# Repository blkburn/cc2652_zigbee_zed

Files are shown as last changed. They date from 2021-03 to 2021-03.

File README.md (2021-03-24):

# Zigbee End Device based on the CC2652R1

This is the complete hardware and software design of a zigbee end device (ZED) designed to be run from a same CR2032 button cell battery.

Texas Instruments Code Composer and the Simplelink SDK is used for development; based on the zed_temperaturesensor_CC26X2R1_LAUNCHXL_tirtos_ccs project.

The hardware design replicates the Launchpad-CC26x2R1 development board as much as possible.

The CC2652R1 is an ultra-low power ARM Cortex process with support for a number of wireless protocols, such as; Thread, Zigbee®, Bluetooth® 5.1 Low Energy, IEEE 802.15.4, IPv6-enabled (6LoWPAN), as well as proprietary protocols including TI 15.4-Stack (2.4 GHz), and simultaneous multi-protocol operation via Dynamic Multiprotocol Manager (DMM).

Development baord power consuption is in line with published datasheet power comsumption figures, allowing the zigbee end device to last many months or years on a single CR2032 battery.

The development board can interface various I2C sensors; a pin breakout is provided to interface the many cheap sensors available on-line. An Adafruit 4-pin STEMMA connector is also provide to connect to an I2C device in their range.

A JTAG header is provided to interface XDS110 (or better) debuggers. A CC1352 Launchpad with built-in XDS110 has been used to debug the development boards.

4-pin bootloader

## Master branch is currently built with:
* CCStudio version: 10.1.1.00004 
* Simplelink_cc13x2_26x2_sdk_4_30_00_54

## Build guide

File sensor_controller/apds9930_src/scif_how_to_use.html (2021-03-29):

# Sensor Controller Studio

## SCIF Driver - How to Use

Introduction

This guide describes how to use the Sensor Controller Interface driver (SCIF) generated from the following Sensor Controller project:

- Project name: APDS9930 I2C Digital Proximity and Ambient Light Sensor
- Project file: C:/Users/BigBob/github/sensor_controller/adps9930.scp
- Operating system: TI-RTOS
- Target chip: CC2652R1F, package QFN48 7x7 RGZ, revision E (2.1)

The guide is tailored for this project, and contains code snippets that you can copy and paste directly into your application.

Preparation

Sensor Controller task code cannot be debugged from the application IDE (IAR EWARM or CCS).

Use Task Testing, Task Debugging and/or Run-Time Logging in Sensor Controller Studio to make sure that your Sensor Controller task(s) work as expected, before you start integrating the SCIF driver into the application.

Getting Started

Follow these steps to start integrating the SCIF driver into your application:

- Add the generated SCIF driver to the application project
- Include the SCIF driver header file
- Add callback functions
- Initialize the SCIF driver
- Start Sensor Controller tasks (simplified)
- Access Sensor Controller data structures from the application
- Handle Sensor Controller ALERT interrupts

Further Integration

These sections cover additional SCIF driver features and other information that can be helpful when integrating the SCIF driver:

- Task control
  - Wait for the previous task control operation to finish
  - Start or restart Sensor Controller tasks
  - Stop Sensor Controller tasks
  - Run Sensor Controller tasks once
  - Trigger the execution code block manually
- Share I/O pins between the Sensor Controller and the application
- Use project specific definitions in the application
- Uninitialize the SCIF driver
- Run the Sensor Controller Studio code generator in the application pre-build step
- Generate Doxygen documentation for the SCIF driver

Getting Started

This section describes how to add and start integrating the SCIF driver into an existing System CPU application.

It is assumed that all the code snippets below go into one C source file, in the same directory as the SCIF driver. Otherwise you may have to change #include paths, and add function prototypes.

If you do not have an existing application, please take a look at some of the examples in Sensor Controller Studio.

Add the Generated SCIF Driver to the Application Project

You must add these files to your application project:

- scif.c
- scif_framework.c

You can optionally add these files to the application project:

- scif.h
- scif_framework.h
- scif_osal_tirtos.c (this source file is mostly for internal use, and is included by scif_framework.c)
- scif_osal_tirtos.h

IAR EWARM

- Right-click in the project tree
- Click Add -> Add Files ...
- Select the files to be added

CCS

- Right-click on the project in the project tree
- Click Add Files ...
- Select the files to be added
- Select the Link to files option (this allows Sensor Controller Studio to update the SCIF driver files)

Include the SCIF Driver Header File

Add the following code to include the SCIF driver main header file:

#include "scif.h"

Add SCIF Driver Callback Functions

Add these SCIF driver callback functions to the application:

// SCIF driver callback: Task control interface ready (non-blocking task control operation completed)
void scCtrlReadyCallback(void) {

}

// SCIF driver callback: Sensor Controller task code has generated an alert interrupt
void scTaskAlertCallback(void) {

}

Initialize the SCIF Driver

Add the following code to initialize the SCIF driver. You can do this:

- In your application's main() function, immediately before the operating system (RTOS) task scheduler is started
- At the start an RTOS task, which has a main loop that handles the Sensor Controller

// Initialize the SCIF operating system abstraction layer
scifOsalInit();
scifOsalRegisterCtrlReadyCallback(scCtrlReadyCallback);
scifOsalRegisterTaskAlertCallback(scTaskAlertCallback);

// Initialize the SCIF driver
scifInit(&scifDriverSetup);

// Enable RTC ticks, with N Hz tick interval
scifStartRtcTicksNow(0x00010000 / N);

I/O Pin Configuration

The scifInit() call initializes all I/O pins used by the Sensor Controller. Do not configure these I/O pins in the application.

Start Sensor Controller Tasks (Simplified)

The SCIF driver uses the task control interface to start and stop Sensor Controller tasks, and perform other task control operations. The Task Control section describes how to use the task control functions correctly, but for now we will only perform one operation that starts the Sensor Controller task.

To start the "I2C Temp and Humidity Sensor" task:

// Start the "I2C Temp and Humidity Sensor" Sensor Controller task
scifStartTasksNbl(1 << SCIF_I2C_TEMP_AND_HUMIDITY_SENSOR_TASK_ID);

Access Sensor Controller Data Structures from the Application

The application can directly access the Sensor Controller's cfg, input, output and state data structures, which are located in the AUX RAM. This is the one and only mechanism for exchanging data between the Sensor Controller and the application.

Resource-specified data structure members should not be accessed directly, but rather through the resource provided API.

I2C Temp and Humidity Sensor

The application will typically read from the output data structure while the task is running:

... = scifTaskData.i2cTempAndHumiditySensor.output.ch0data;
... = scifTaskData.i2cTempAndHumiditySensor.output.ch1data;
... = scifTaskData.i2cTempAndHumiditySensor.output.status;

Handle Sensor Controller ALERT interrupts

You can handle Sensor Controller ALERT events at any desired priority level, for example:

- In interrupt context, that is, in scTaskAlertCallback()
- In RTOS task context, using scTaskAlertCallback() to unblock the task by posting a semaphore or similar

// Clear the ALERT interrupt source
scifClearAlertIntSource();

... Access Sensor Controller task data structures here ...

// Acknowledge the ALERT event
scifAckAlertEvents();

Further Integration

This section describes task control in more detail, additional SCIF driver features, and other useful information.

Task Control

Task control operations are used to start and stop Sensor Controller tasks, and to trigger manual execution of task code blocks.

The task control interface can perform one operation at a time, and it is busy until the Sensor Controller has completed the operation. The task control functions are, however, non-blocking (hence the Nbl suffix), and return immediately. This means that you must wait for each task control operation to finish before performing another operation.

You can wait either before or after each task control operation. Normally it makes sense to wait before each operation since this reduces the waiting time. If your application performs task control from multiple threads of execution, you must ensure that this is done atomically:

1. Enter critical section
2. Wait for the previous task control operation to finish
3. Perform task control operation, for example start Sensor Controller tasks
4. Leave critical section

Wait for the Previous Task Control Operation to Finish

This code waits until the previous task control operation has finished, with a timeout in microseconds. The timeout is application specific. The function returns immediately if task control interface already is ready.

// Wait with 20 millisecond timeout
if (scifWaitOnNbl(20000) != SCIF_SUCCESS) {
    ... Handle timeout or usage error (see the function documentation) ...
} else {
    ... Perform the next task control operation, for example start Sensor Controller tasks ...
}

Start or Restart Sensor Controller Tasks

Starting a Sensor Controller task triggers the Initialization code. The task is then active.

After a Sensor Controller task has been stopped (see below), you must reset the task's data structures before it can be restarted. The scifResetTaskStructs() function will always reset the state data structure. You can optionally also reset the cfg, input and output data structures.

Do the following to (re)start a Sensor Controller task:

- To start or restart the "I2C Temp and Humidity Sensor" task:

// Reset all data structures except configuration
scifResetTaskStructs(1 << SCIF_I2C_TEMP_AND_HUMIDITY_SENSOR_TASK_ID, (1 << SCIF_STRUCT_INPUT) | (1 << SCIF_STRUCT_OUTPUT));

// (Re)start the "I2C Temp and Humidity Sensor" Sensor Controller task
if (scifWaitOnNbl(20000) != SCIF_SUCCESS) {
    ... Handle timeout or usage error ...
} else if (scifStartTasksNbl(1 << SCIF_I2C_TEMP_AND_HUMIDITY_SENSOR_TASK_ID) != SCIF_SUCCESS) {
    ... Handle usage error ...
}

Stop Sensor Controller Tasks

Stopping a Sensor Controller task triggers the Termination code. The task is then inactive.

Do the following to stop a Sensor Controller task:

- To stop the "I2C Temp and Humidity Sensor" task:

// Stop the "I2C Temp and Humidity Sensor" Sensor Controller task
if (scifWaitOnNbl(20000) != SCIF_SUCCESS) {
    ... Handle timeout or usage error ...
} else if (scifStopTasksNbl(1 << SCIF_I2C_TEMP_AND_HUMIDITY_SENSOR_TASK_ID) != SCIF_SUCCESS) {
    ... Handle usage error ...
}

Run Sensor Controller Tasks Once

Running a Sensor Controller task once triggers the Initialization Code, the Execution Code (one time), and the Termination Code.

Do the following to run a Sensor Controller task once:

- To run the "I2C Temp and Humidity Sensor" task:

// Run the "I2C Temp and Humidity Sensor" Sensor Controller task
if (scifWaitOnNbl(20000) != SCIF_SUCCESS) {
    ... Handle timeout or usage error ...
} else if (scifExecuteTasksOnceNbl(1 << SCIF_I2C_TEMP_AND_HUMIDITY_SENSOR_TASK_ID) != SCIF_SUCCESS) {
    ... Handle usage error ...
}

Trigger the Execution Code Block Manually

For an active task, it is possible to trigger the Execution Code manually.

Do the following to trigger a single iteration of the Execution Code:

- To run the "I2C Temp and Humidity Sensor" task's Execution Code:

// Run the "I2C Temp and Humidity Sensor" Execution Code
if (scifWaitOnNbl(20000) != SCIF_SUCCESS) {
    ... Handle timeout or usage error ...
} else if (scifSwTriggerExecutionCodeNbl(1 << SCIF_I2C_TEMP_AND_HUMIDITY_SENSOR_TASK_ID) != SCIF_SUCCESS) {
    ... Handle usage error ...
}

Share I/O Pins Between the Sensor Controller and the Application

In some applications you may want to transfer ownership of I/O pins between the Sensor Controller and MCU domain peripherals, for example when:

- The Sensor Controller and the application need to access different I2C devices over the same SCL and SDA lines
- The Sensor Controller and the application need to access different SPI devices over the same SCLK, MOSI and MISO lines, but with different chip select pins

To transfer I/O pins from Sensor Controller task(s) to the application:

- Stop the Sensor Controller task(s) that are currently using the I/O pins
- You can now open the TI driver(s) that require the I/O pins. An additional step is required for regular GPIO functions:
  - The TI PIN driver assumes that unused I/O pins are mapped to the GPIO hardware module, but that is not the case for Sensor Controller I/O pins. For regular GPIO functions, add the following code after the I/O pin(s) have been opened with the PIN driver:

// For each affected I/O pin:
PINCC26XX_setMux(pinHandle, pin, PINCC26XX_MUX_GPIO);

To transfer I/O pins from the application back to Sensor Controller tasks:

- Close the TI driver(s) that are currently using the I/O pins
- Move I/O pin ownership back to the Sensor Controller task(s):
  - For the I2C Temp and Humidity Sensor task, call:

scifReinitTaskIo(1 << SCIF_I2C_TEMP_AND_HUMIDITY_SENSOR_TASK_ID);
- You can now restart the Sensor Controller task(s)

Use Project Specific Definitions in the Application

The SCIF Driver provides these definitions for use in the application:

- Target chip identification
  - SCIF_TARGET_CHIP_NAME_CC2652R1F (no value)
  - SCIF_TARGET_CHIP_PACKAGE_QFN48_7X7_RGZ (no value)
- Number of tasks
  - SCIF_TASK_COUNT
- Task IDs
  - SCIF_I2C_TEMP_AND_HUMIDITY_SENSOR_TASK_ID
- User-specified constants
  - SCIF_I2C_TEMP_AND_HUMIDITY_SENSOR_ATIME
  - SCIF_I2C_TEMP_AND_HUMIDITY_SENSOR_AUTO_INC
  - SCIF_I2C_TEMP_AND_HUMIDITY_SENSOR_CH0DATA
  - SCIF_I2C_TEMP_AND_HUMIDITY_SENSOR_CH1DATA
  - SCIF_I2C_TEMP_AND_HUMIDITY_SENSOR_CMD
  - SCIF_I2C_TEMP_AND_HUMIDITY_SENSOR_CONFIG
  - SCIF_I2C_TEMP_AND_HUMIDITY_SENSOR_CONTROL
  - SCIF_I2C_TEMP_AND_HUMIDITY_SENSOR_ENABLE
  - SCIF_I2C_TEMP_AND_HUMIDITY_SENSOR_I2C_ADDR
  - SCIF_I2C_TEMP_AND_HUMIDITY_SENSOR_PTIME
  - SCIF_I2C_TEMP_AND_HUMIDITY_SENSOR_STATUS
  - SCIF_I2C_TEMP_AND_HUMIDITY_SENSOR_WTIME
- I/O mapping
  - SCIF_I2C_TEMP_AND_HUMIDITY_SENSOR_DIO_I2C_SCL
  - SCIF_I2C_TEMP_AND_HUMIDITY_SENSOR_DIO_I2C_SDA

Uninitialize the SCIF Driver

It is possible to include multiple SCIF driver setups (that is, outputs from multiple Sensor Controller projects) in one application.

To switch driver setup, first stop using and uninitialize this SCIF driver:

// Stop all Sensor Controller tasks
if (scifWaitOnNbl(20000) != SCIF_SUCCESS) {
    ... Handle error...
} else if (scifStopTasksNbl((1 << SCIF_I2C_TEMP_AND_HUMIDITY_SENSOR_TASK_ID)) != SCIF_SUCCESS) {
    ... Handle error...
} else if (scifWaitOnNbl(20000) != SCIF_SUCCESS) {
    ... Handle error...

} else {
    // All tasks have been stopped successfully

    // Disable RTC ticks
    scifStopRtcTicks();

    // Uninitialize the SCIF driver (includes I/O configuration)
    scifUninit();
}

Then initialize the other SCIF driver, as described in its "How to Use" guide.

I/O Pin Configuration

The scifUninit() call uninitializes all Sensor Controller I/O pins. The I/O pins will be reverted to regular GPIO inputs, with pull as configured in the Sensor Controller Studio task panel(s).

Run Sensor Controller Studio Code Generator During Application Pre-Build Step

Use the Sensor Controller Studio command line interface (CLI) to ensure that the generated SCIF driver is up-to-date.

The -s parameter prevents file output when existing files already are up-to-date.

IAR EWARM

- Right-click on the project in the project tree
- Click Options...
- Select Build Actions
- Add the following to the pre-build step (you may need to create a batch file if you have multiple pre-build steps):

"C:\Program Files (x86)\Texas Instruments\Sensor Controller Studio\bin\sensor_controller_studio_cli.exe" -g "C:/Users/BigBob/github/sensor_controller/adps9930.scp" -s -q

CCS

- Right-click on the project in the project tree
- Click Options...
- Select Build
- Add the following to the pre-build steps:

"C:/Program Files (x86)/Texas Instruments/Sensor Controller Studio/bin/sensor_controller_studio_cli.exe" -g "C:/Users/BigBob/github/sensor_controller/adps9930.scp" -s -q

Generate Doxygen HTML Documentation for the SCIF Driver

Doxygen generates HTML documentation based on specially formatted comments in source code. Download Doxygen from http://www.doxygen.org/.

Set the path to doxygen.exe in the Preferences panel if needed. The current path is C:/Program Files/doxygen/bin/doxygen.exe.

To create or update the HTML documentation, run scif_run_doxygen.bat. The generated documentation can then be found here: scif_dox/index.html

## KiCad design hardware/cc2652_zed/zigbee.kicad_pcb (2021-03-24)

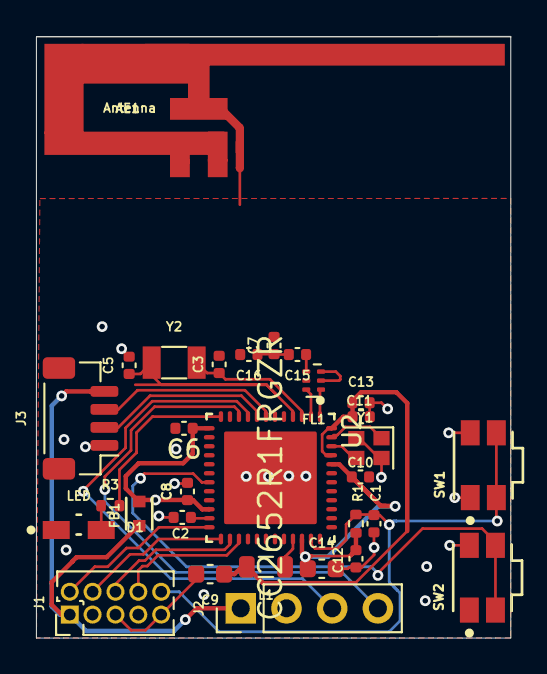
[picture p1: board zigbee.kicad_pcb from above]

Board: 4 copper layers, 26.3 x 33.4 mm, 31 parts (1 on the bottom side), 27 nets.

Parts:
AE1: Antenna; 2.4GHz-INVERTED-F-ANTENNA
BT1: BAT-HLD-001; Linx-BAT-HLD-001-0
C1, C6, C8, C10, C11, C12, C13: 100n; C_0402_1005Metric
C2, C3, C5: 12p; C_0402_1005Metric
C7, C15, C16: CAP; C_0402_1005Metric
C9, C14: 22u; C_0603_1608Metric
D1: LED; Lite-On-LTST-S220KRKT-0-0-0
FB1: BLM18HE152SN1D; Murata-BLM18-0.15-t0.8-0-0-MFG
FL1: 2450BM14G; Balun_Johanson_1.6x0.8mm
J1: Conn_02x05_Odd_Even; PinHeader_2x05_P1.27mm_Vertical
J2: Conn_01x04; PinHeader_1x04_P2.54mm_Vertical
J3: Conn_01x04; JST_SH_BM04B-SRSS-TB_1x04-1MP_P1.00mm_Vertical
L1: L; L_0805_2012Metric
R1: 100k; R_0402_1005Metric
R3: 150; R_0402_1005Metric
SW1, SW2: EVQ-P7A01P-switch2; Panasonic-EVQ-P7A01P-0-0-MFG
U2: CC2652R1FRGZR; Texas_Instruments-CC2652R1FRGZR-MFG
Y1: Crystal_GND24; Crystal_SMD_2016-4Pin_2.0x1.6mm
Y2: Crystal; Crystal_SMD_3215-2Pin_3.2x1.5mm

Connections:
/DCDC_SW: L1.1, U2.33
/GLED: R3.2, U2.12
/RXD: J3.3, U2.7
/SCL: J2.3, U2.9
/SDA: J2.4, U2.10
/TCKC: J1.4, U2.25
/TDI: J1.8, U2.27
/TDO: J1.6, U2.26
/TMSC: J1.2, U2.24
/TXD: J3.2, U2.8
/X32K_Q1: C3.1, U2.3, Y2.1
/X32K_Q2: C5.1, U2.4, Y2.2
/nReset: C1.1, J1.10, R1.2, SW1.2, SW1.2', U2.35
GND: AE1.2, BT1.1, C1.2, C2.1, C3.2, C5.2, C6.2, C7.2, C8.2, C9.2, C10.2, C11.2, C12.2, C13.2, C14.2, D1.1, FL1.5, FL1.6, J1.3, J1.5, J1.9, J2.2, J3.1, SW1.1, SW1.1', SW2.1, SW2.1', U2.49, Y1.2, Y1.4
unnamed: AE1.1, C16.2
unnamed: C2.2, U2.23
unnamed: C15.1, FL1.1
unnamed: C7.1, C15.2, C16.1
unnamed: D1.2, R3.1
unnamed: FL1.3, U2.2
unnamed: FL1.4, U2.1
unnamed: SW2.2, SW2.2', U2.19
unnamed: U2.46, Y1.3
unnamed: U2.47, Y1.1
VDD: BT1.2, FB1.1, J1.1, J2.1, J3.4
VDDR: C9.1, C11.1, C13.1, L1.2, U2.45, U2.48
VDDS: C6.1, C8.1, C10.1, C12.1, C14.1, FB1.2, R1.1, U2.13, U2.22, U2.34, U2.44

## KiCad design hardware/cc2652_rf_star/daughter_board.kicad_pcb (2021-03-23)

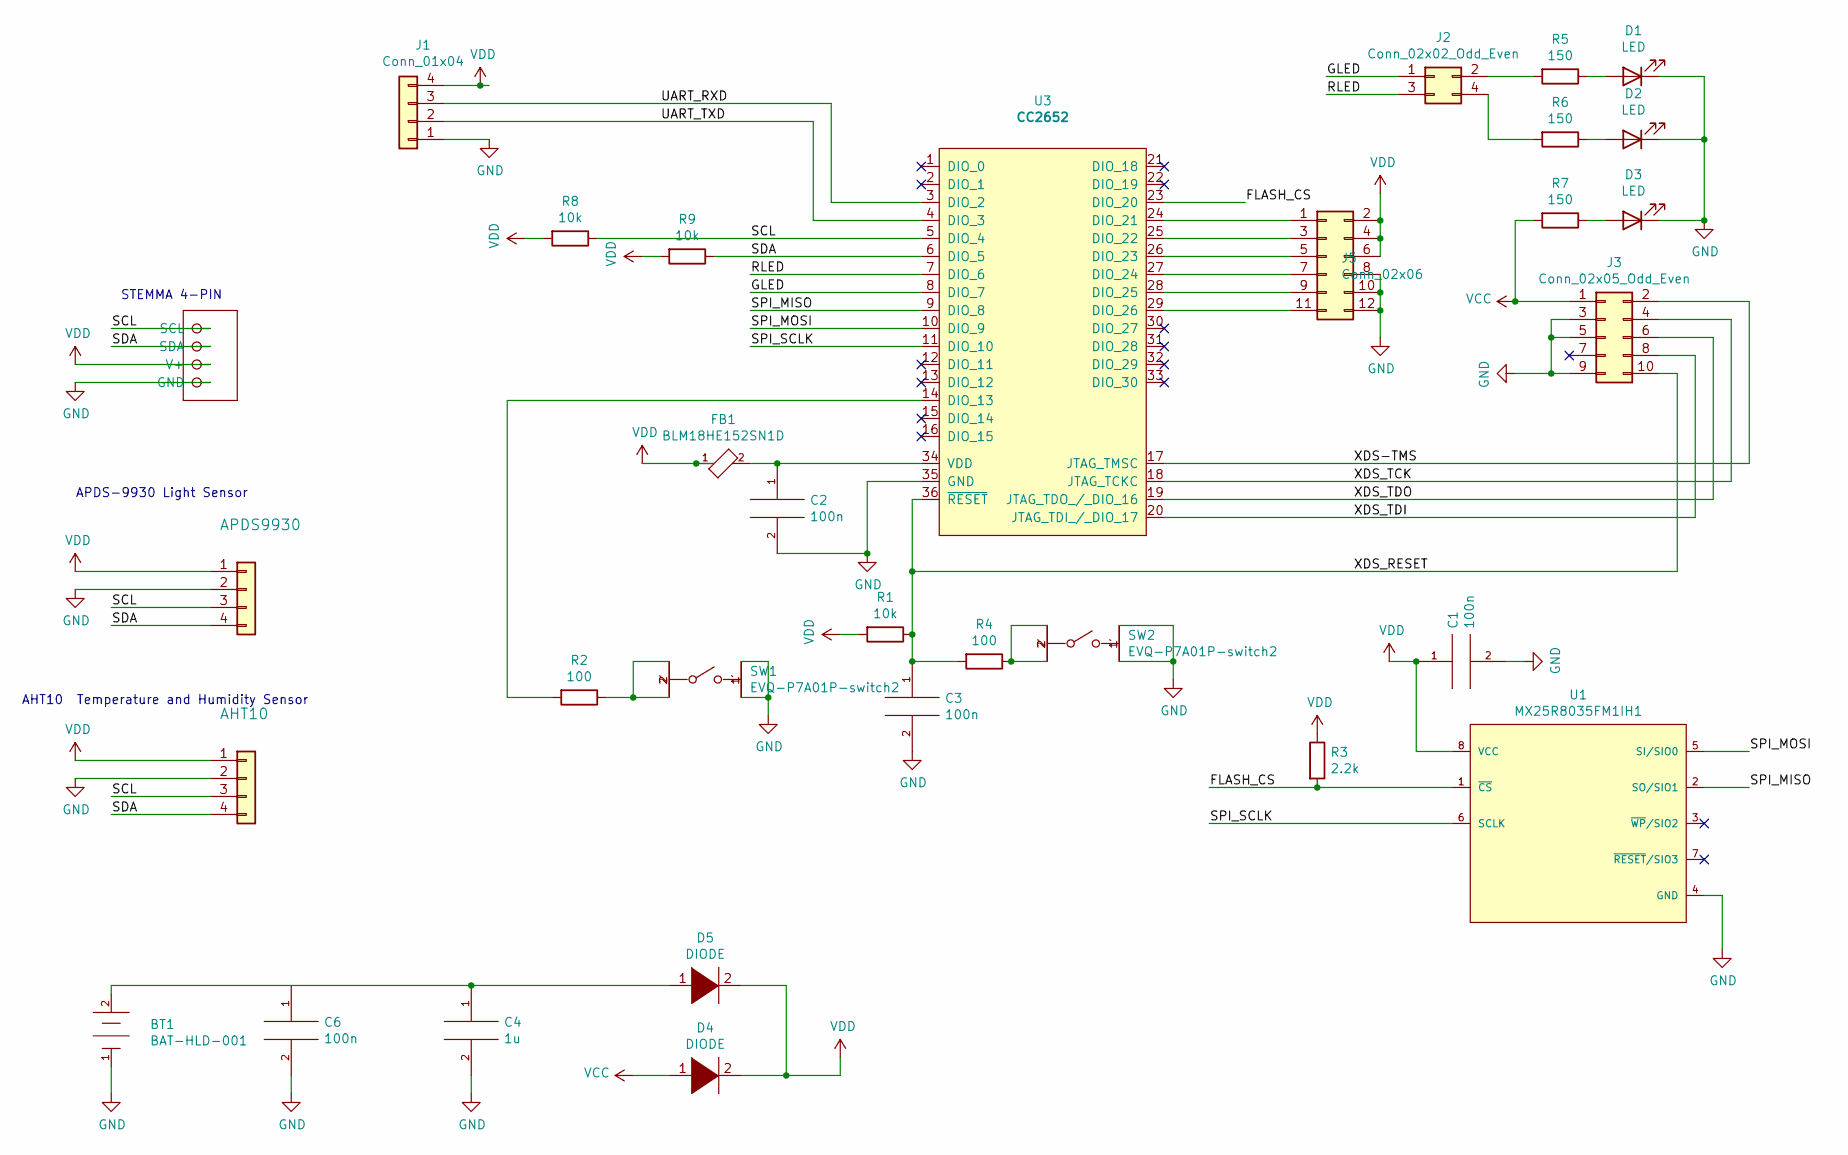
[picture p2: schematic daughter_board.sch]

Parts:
AHT10: Conn_01x04; PinHeader_1x04_P2.54mm_Vertical
APDS9930: Conn_01x04; PinHeader_1x04_P2.54mm_Vertical
BT1: BAT-HLD-001; Linx-BAT-HLD-001-0; mouser part number 712-BAT-HLD-001; digikey description HOLDER BATTERY 20MM COIN
C1, C2, C3, C6: 100n; C_0805_2012Metric
C4: 1u; C_0805_2012Metric
D1, D2, D3: LED; Lite-On-LTST-S220KRKT-0-0-0
D4, D5: DIODE; SOD-123FL
FB1: BLM18HE152SN1D; R_0603_1608Metric_Pad0.98x0.95mm_HandSolder; tolerance 25%
J1: Conn_01x04; PinHeader_1x04_P2.54mm_Vertical
J2: Conn_02x02_Odd_Even; PinHeader_2x02_P2.54mm_Vertical
J3: Conn_02x05_Odd_Even; PinHeader_2x05_P1.27mm_Vertical
J5: Conn_02x06; PinHeader_2x06_P2.54mm_Vertical
R1, R8, R9: 10k; R_0805_2012Metric
R2, R4: 100; R_0805_2012Metric
R3: 2.2k; R_0805_2012Metric
R5, R6, R7: 150; R_0805_2012Metric
STEMMA1: STEMMA_I2C_QT; JST_SH_BM04B-SRSS-TB_1x04-1MP_P1.00mm_Vertical
SW1, SW2: EVQ-P7A01P-switch2; Panasonic-EVQ-P7A01P-0-0-MFG; voltage rating DC 12V; mouser part number 667-EVQP7A01P; digikey description SWITCH TACTILE SPST-NO 0.05A 12V
U1: MX25R8035FM1IH1; SOP-8_3.9x4.9mm_P1.27mm; digikey description IC FLASH 8M SPI 33MHZ 8USON
U3: CC2652; rf_star_cc2652

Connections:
/FLASH_CS: R3.2, U1.1 (~CS~), U3.23 (DIO_20)
/GLED: J2.1, U3.8 (DIO_7)
/RLED: J2.3, U3.7 (DIO_6)
/SCL: AHT10.3, APDS9930.3, R8.1, STEMMA1.4 (SCL), U3.5 (DIO_4)
/SDA: AHT10.4, APDS9930.4, R9.1, STEMMA1.3 (SDA), U3.6 (DIO_5)
/SPI_MISO: U1.2 (SO/SIO1), U3.9 (DIO_8)
/SPI_MOSI: U1.5 (SI/SIO0), U3.10 (DIO_9)
/SPI_SCLK: U1.6 (SCLK), U3.11 (DIO_10)
/UART_RXD: J1.3, U3.3 (DIO_2)
/UART_TXD: J1.2, U3.4 (DIO_3)
/XDS-TMS: J3.2, U3.17 (JTAG_TMSC)
/XDS_RESET: C3.1, J3.10, R1.1, R4.2, U3.36 (~RESET)
/XDS_TCK: J3.4, U3.18 (JTAG_TCKC)
/XDS_TDI: J3.8, U3.20 (JTAG_TDI_/_DIO_17)
/XDS_TDO: J3.6, U3.19 (JTAG_TDO_/_DIO_16)
GND: AHT10.2, APDS9930.2, BT1.1 (CATHODE), C1.2, C2.2, C3.2, C4.2, C6.2, D1.1 (K), D2.1 (K), D3.1 (K), J1.1, J3.3, J3.5, J3.9, J5.8, J5.10, J5.12, STEMMA1.1 (GND), SW1.1, SW1.1', SW2.1, SW2.1', U1.4 (GND), U3.35 (GND)
unnamed: BT1.2 (ANODE), C4.1, C6.1, D5.1 (K)
unnamed: C2.1, FB1.2, U3.34 (VDD)
unnamed: D1.2 (A), R5.1
unnamed: D2.2 (A), R6.1
unnamed: D3.2 (A), R7.1
unnamed: J2.2, R5.2
unnamed: J2.4, R6.2
unnamed: J5.1, U3.24 (DIO_21)
unnamed: J5.3, U3.25 (DIO_22)
unnamed: J5.5, U3.26 (DIO_23)
unnamed: J5.7, U3.27 (DIO_24)
unnamed: J5.9, U3.28 (DIO_25)
unnamed: J5.11, U3.29 (DIO_26)
unnamed: R2.1, SW1.2, SW1.2'
unnamed: R2.2, U3.14 (DIO_13)
unnamed: R4.1, SW2.2, SW2.2'
VCC: D4.1 (K), J3.1, R7.2
VDD: AHT10.1, APDS9930.1, C1.1, D4.2 (A), D5.2 (A), FB1.1, J1.4, J5.2, J5.4, J5.6, R1.2, R3.1, R8.2, R9.2, STEMMA1.2 (V+), U1.8 (VCC)

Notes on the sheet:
STEMMA 4-PIN
APDS-9930 Light Sensor
AHT10 Temperature and Humidity Sensor

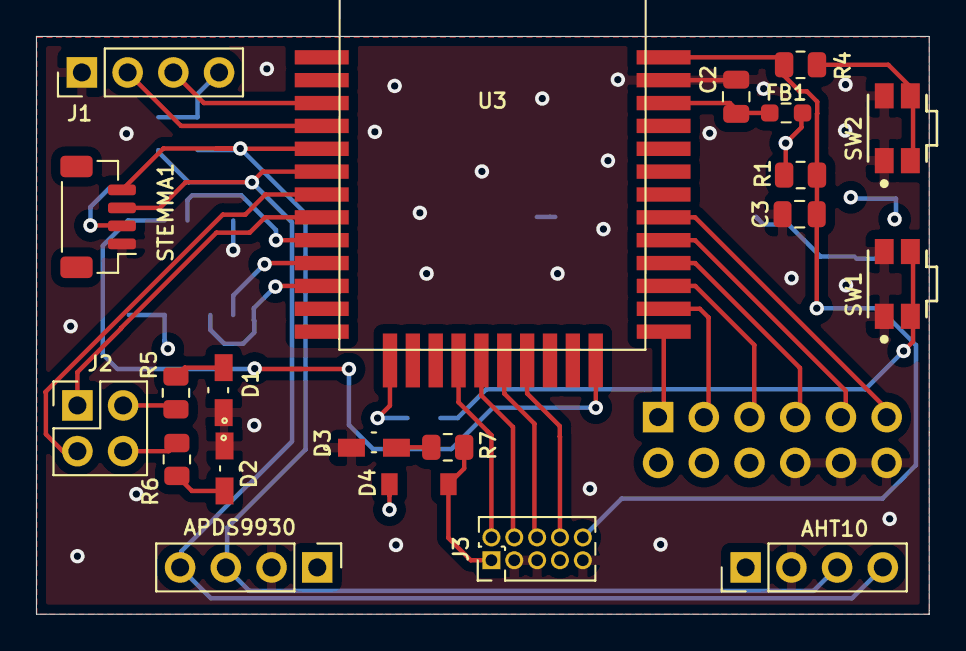
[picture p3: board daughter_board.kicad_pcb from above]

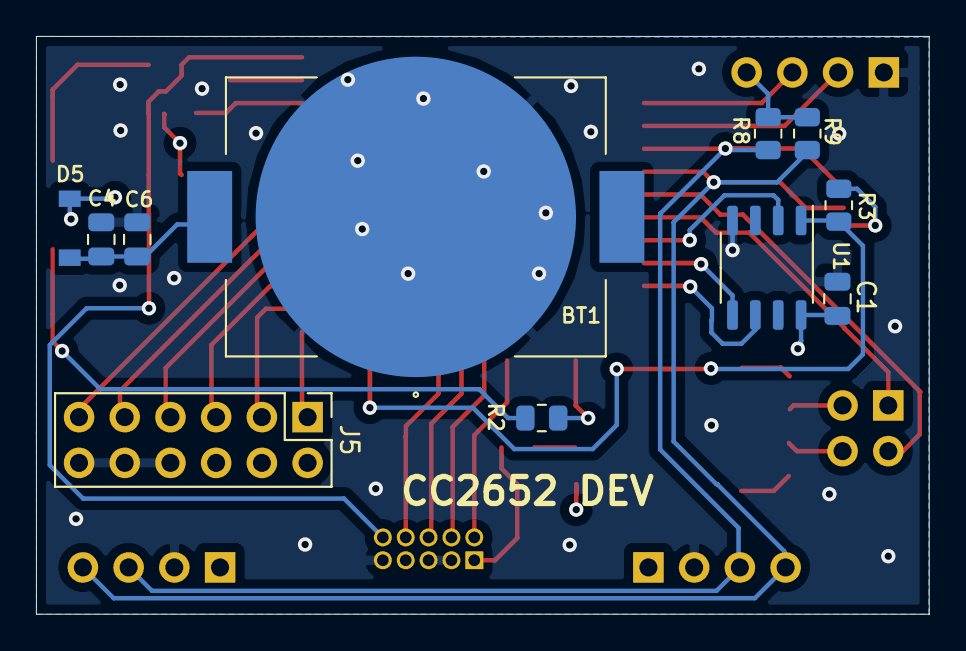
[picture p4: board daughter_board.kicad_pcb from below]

Board: 4 copper layers, 49.6 x 32.1 mm, 32 parts (11 on the bottom side), 34 nets.

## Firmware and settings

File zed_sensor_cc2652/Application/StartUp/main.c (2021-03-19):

/******************************************************************************

 @file main.c

 @brief main entry of the example application

 Group: WCS LPC
 Target Device: CC2652

 ******************************************************************************

 Copyright (c) 2016-2017, Texas Instruments Incorporated
 All rights reserved.

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
 *  Neither the name of Texas Instruments Incorporated nor the names of
    its contributors may be used to endorse or promote products derived
    from this software without specific prior written permission.

 THIS SOFTWARE IS PROVIDED BY THE COPYRIGHT HOLDERS AND CONTRIBUTORS "AS IS"
 AND ANY EXPRESS OR IMPLIED WARRANTIES, INCLUDING, BUT NOT LIMITED TO,
 THE IMPLIED WARRANTIES OF MERCHANTABILITY AND FITNESS FOR A PARTICULAR
 PURPOSE ARE DISCLAIMED. IN NO EVENT SHALL THE COPYRIGHT OWNER OR
 CONTRIBUTORS BE LIABLE FOR ANY DIRECT, INDIRECT, INCIDENTAL, SPECIAL,
 EXEMPLARY, OR CONSEQUENTIAL DAMAGES (INCLUDING, BUT NOT LIMITED TO,
 PROCUREMENT OF SUBSTITUTE GOODS OR SERVICES; LOSS OF USE, DATA, OR PROFITS;
 OR BUSINESS INTERRUPTION) HOWEVER CAUSED AND ON ANY THEORY OF LIABILITY,
 WHETHER IN CONTRACT, STRICT LIABILITY, OR TORT (INCLUDING NEGLIGENCE OR
 OTHERWISE) ARISING IN ANY WAY OUT OF THE USE OF THIS SOFTWARE,
 EVEN IF ADVISED OF THE POSSIBILITY OF SUCH DAMAGE.

 ******************************************************************************
 Release Name: simplelink_zigbee_sdk_plugin_0_95_00_18_s
 Release Date: 2017-11-10 13:43:40
 *****************************************************************************/

/******************************************************************************
 Includes
 *****************************************************************************/

#include <string.h>
#include <xdc/std.h>

#include <xdc/runtime/Error.h>
#include <xdc/runtime/System.h>
#include <ti/sysbios/knl/Semaphore.h>
#include <ti/sysbios/BIOS.h>
#include <ti/sysbios/knl/Task.h>

#include <ioc.h>

#include "sys_ctrl.h"

#include "ti_drivers_config.h"
#include <inc/hw_ccfg.h>
#include <inc/hw_ccfg_simple_struct.h>

/* Header files required for the temporary idle task function */
#include <ti/drivers/Power.h>
#include <ti/drivers/power/PowerCC26XX.h>
#include <aon_rtc.h>
#include <prcm.h>

#ifndef TIMAC_ROM_IMAGE_BUILD
#include "crypto_mac_api.h"
#endif
#include <chipinfo.h>

/* Header files required to enable instruction fetch cache */
#include <vims.h>
#include <hw_memmap.h>

#include <ti/sysbios/hal/Hwi.h>

#include "cpu.h"

#include "nvocmp.h"

#include "zstackconfig.h"

#ifdef ZSTACK_GPD
#include "macTask.h"
#else
#include "zstackstartup.h"
#include "zstackapi.h"
#endif

#ifndef CUI_DISABLE
#include "cui.h"
#endif


#include "ti_zstack_config.h"

/******************************************************************************
 Constants
 *****************************************************************************/
#define CONFIG_PHY_ID 0

/* Assert Reasons */
#define MAIN_ASSERT_STACK        2
#define MAIN_ASSERT_MAC          3
#define MAIN_ASSERT_HWI_TIRTOS   4

#define RFC_MODE_BLE                 PRCM_RFCMODESEL_CURR_MODE1
#define RFC_MODE_IEEE                PRCM_RFCMODESEL_CURR_MODE2
#define RFC_MODE_ANT                 PRCM_RFCMODESEL_CURR_MODE4
#define RFC_MODE_EVERYTHING_BUT_ANT  PRCM_RFCMODESEL_CURR_MODE5
#define RFC_MODE_EVERYTHING          PRCM_RFCMODESEL_CURR_MODE6

/* Extended Address offset in FCFG (LSB..MSB) */
#define EXTADDR_OFFSET 0x2F0


#define APP_TASK_STACK_SIZE 3000

#define SET_RFC_MODE(mode) HWREG( PRCM_BASE + PRCM_O_RFCMODESEL ) = (mode)

// Exented Address Length
#define EXTADDR_LEN 8

// Macro used to break a uint32_t into individual bytes
//#define BREAK_UINT32(var, ByteNum) \
//    (uint8_t)((uint32_t)(((var) >> ((ByteNum) * 8)) & 0x00FF))

/******************************************************************************
 External Variables
 *****************************************************************************/
#ifdef ZSTACK_GPD
extern ApiMac_sAddrExt_t ApiMac_extAddr;
#endif

/******************************************************************************
 Global Variables
 *****************************************************************************/

// ZNP does not need an application task
#ifndef ZNP_NPI
Task_Struct myTask;
Char myTaskStack[APP_TASK_STACK_SIZE];
// add sensor task info
Task_Struct mySensorTask;
Char mySensorTaskStack[APP_TASK_STACK_SIZE];
#endif

#ifndef TIMAC_ROM_IMAGE_BUILD
/* Crypto driver function table */
uint32_t *macCryptoDrvTblPtr = (uint32_t*)macCryptoDriverTable;
#endif

/*
 When assert happens, this field will be filled with the reason:
       MAIN_ASSERT_HWI_TIRTOS,
       MAIN_ASSERT_STACK,
       MAIN_ASSERT_MAC
 */
uint8_t Main_assertReason = 0;

/******************************************************************************
 * ZStack Configuration Structure
 */
zstack_Config_t zstack_user0Cfg =
{
    {0, 0, 0, 0, 0, 0, 0, 0}, // Extended Address
    {0, 0, 0, 0, 0, 0, 0, 0}, // NV function pointers
    0,                        // Application thread ID
    0,                        // stack image init fail flag
    MAC_USER_CFG
};

/* Stack TIRTOS Task semaphore */
Semaphore_Struct npiInitializationMutex;
Semaphore_Handle npiInitializationMutexHandle;

/******************************************************************************
 Local Variables
 *****************************************************************************/

#ifdef ZSTACK_GPD
uint8_t _macTaskId;
#elif !defined (ZNP_NPI)
static uint8_t stackServiceTaskId;
#endif

/*!
 * @brief       Fill in your own assert function.
 *
 * @param       assertReason - reason: MAIN_ASSERT_HWI_TIRTOS,
 *                                     MAIN_ASSERT_STACK, or
 *                                     MAIN_ASSERT_MAC
 */
void Main_assertHandler(uint8_t assertReason)
{
    Main_assertReason = assertReason;

#if defined(RESET_ASSERT)
     /* Pull the plug and start over */
    SysCtrlSystemReset();
#else
    Hwi_disable();
    char assertLine[21] = {'\0'};
    System_snprintf(assertLine, 21, "[Assert Reason] 0x%02X", assertReason);
    while(1)
    {
        /* Put you code here to do something if in assert */
        #ifndef CUI_DISABLE
        CUI_assert(assertLine, TRUE);
        #endif
    }
#endif
}

/*!
 * @brief       Main task function
 *
 * @param       a0 -
 * @param       a1 -
 */
#ifndef ZNP_NPI
Void taskFxn(UArg a0, UArg a1)
{
#if defined(USE_CACHE_RAM)
    /* Retain the Cache RAM */
    Power_setConstraint(PowerCC26XX_SB_VIMS_CACHE_RETAIN);
#endif

#ifdef ZSTACK_GPD

#else
    /* get the service taskId of the Stack */
    stackServiceTaskId = stackTask_getStackServiceId();
    /* configure the message API the application will use to communicate with
       the stack */
    Zstackapi_init(stackServiceTaskId);
#endif

    /* Kick off application */
    extern void sampleApp_task(NVINTF_nvFuncts_t *pfnNV);
    sampleApp_task(&zstack_user0Cfg.nvFps);
}

/////////////// add sensor task
Void taskSensorFxn(UArg a0, UArg a1)
{
    /* Kick off application */
    extern void sensorApp_task();
    sensorApp_task();

}

#endif

/*!
 * @brief       TIRTOS HWI Handler.  The name of this function is set to
 *              M3Hwi.excHandlerFunc in app.cfg, you can disable this by
 *              setting it to null.
 *
 * @param       excStack - TIROS variable
 * @param       lr - TIROS variable
 */
xdc_Void Main_excHandler(UInt *excStack, UInt lr)
{
    /* User defined function */
    Main_assertHandler(MAIN_ASSERT_HWI_TIRTOS);
}

/*!
 * @brief       HAL assert handler required by OSAL memory module.
 */
void assertHandler(void)
{
    /* User defined function */
    Main_assertHandler(MAIN_ASSERT_MAC);
}

/*!
 * @brief       Callback function when voltage is lower than NVOCMP_MIN_VDD_FLASH_MV
 *              during an NV write operation
 *
 * @param       voltage - Measured device voltage
 */
#ifdef NVOCMP_MIN_VDD_FLASH_MV
void Main_lowVoltageCb(uint32_t voltage)
{
    /* Implement any safety precautions for application due to low voltage detected */
}
#endif

/*!
 * @brief       "main()" function - starting point
 */
int main()
{
#ifndef USE_DEFAULT_USER_CFG
    zstack_user0Cfg.macConfig.pAssertFP = assertHandler;
#endif

    /* enable iCache prefetching */
    VIMSConfigure(VIMS_BASE, TRUE, TRUE);

#if defined(USE_CACHE_RAM)
    /* Disable cache */
    VIMSModeSet( VIMS_BASE, VIMS_MODE_DISABLED);
#else
    /* Enable cache */
    VIMSModeSet( VIMS_BASE, VIMS_MODE_ENABLED);
#endif

    /*
     Initialization for board related stuff such as LEDs
     following TI-RTOS convention
     */
    Board_initGeneral();

// OTA client projects use BIM, so CCFG isn't present in this image
#if !((defined OTA_CLIENT_STANDALONE) || (defined OTA_CLIENT_INTEGRATED))
    /*
     * Copy the extended address from the CCFG area
     * Assumption: the memory in CCFG_IEEE_MAC_0 and CCFG_IEEE_MAC_1
     * is contiguous and LSB first.
     */
    /* Used to check for a valid extended address */
    static const uint8_t dummyExtAddr[] =
        { 0xFF, 0xFF, 0xFF, 0xFF, 0xFF, 0xFF, 0xFF, 0xFF };

    OsalPort_memcpy(zstack_user0Cfg.extendedAddress, (uint8_t *)&(__ccfg.CCFG_IEEE_MAC_0),
           (APIMAC_SADDR_EXT_LEN));
    /* Check to see if the CCFG IEEE is valid */
    if(memcmp(zstack_user0Cfg.extendedAddress, dummyExtAddr, APIMAC_SADDR_EXT_LEN) == 0)
#endif // (defined OTA_CLIENT_STANDALONE) || (defined OTA_CLIENT_INTEGRATED
    {
        /* No, it isn't valid.  Get the Primary IEEE Address */
        OsalPort_memcpy(zstack_user0Cfg.extendedAddress, (uint8_t *)(FCFG1_BASE + EXTADDR_OFFSET),
                       (APIMAC_SADDR_EXT_LEN));
    }

    /* Setup the NV driver */
    NVOCMP_loadApiPtrs(&zstack_user0Cfg.nvFps);
#ifdef NVOCMP_MIN_VDD_FLASH_MV
    NVOCMP_setLowVoltageCb(&Main_lowVoltageCb);
#endif
    if(zstack_user0Cfg.nvFps.initNV)
    {
        zstack_user0Cfg.nvFps.initNV(NULL);
    }

#ifdef ZSTACK_GPD
    OsalPort_memcpy(ApiMac_extAddr, zstack_user0Cfg.extendedAddress,
           (APIMAC_SADDR_EXT_LEN));
    _macTaskId = macTaskInit(&zstack_user0Cfg.macConfig);
#else
    /* configure stack task */
    stackTask_init(&zstack_user0Cfg);
#endif // ZSTACK_GPD

#ifdef NPI
    extern void NPITask_createTask(void);
    NPITask_createTask();

    Semaphore_Params semParam;
    Semaphore_Params_init(&semParam);
    semParam.mode = ti_sysbios_knl_Semaphore_Mode_COUNTING;
    Semaphore_construct(&npiInitializationMutex, 0, &semParam);
    npiInitializationMutexHandle = Semaphore_handle(&npiInitializationMutex);
#endif

// ZNP does not need an application task
#ifndef ZNP_NPI

#ifndef CUI_DISABLE
    CUI_params_t cuiParams;

    CUI_paramsInit(&cuiParams);
    CUI_init(&cuiParams);
#endif
    Task_Params taskParams;

    /* Configure app task. */
    Task_Params_init(&taskParams);
    taskParams.stack = myTaskStack;
    taskParams.stackSize = APP_TASK_STACK_SIZE;
    taskParams.priority = 2;
    Task_construct(&myTask, taskFxn, &taskParams, NULL);

    ////////////////////////////// added sensor task
    /* Configure sensor task. */
    Task_Params taskSesnorParams;
    Task_Params_init(&taskSesnorParams);
    taskSesnorParams.stack = mySensorTaskStack;
    taskSesnorParams.stackSize = APP_TASK_STACK_SIZE;
    taskSesnorParams.priority = 2;
    Task_construct(&mySensorTask, taskSensorFxn, &taskSesnorParams, NULL);

#endif

#ifdef DEBUG_SW_TRACE
    IOCPortConfigureSet(IOID_8, IOC_PORT_RFC_TRC, IOC_STD_OUTPUT
                    | IOC_CURRENT_4MA | IOC_SLEW_ENABLE);
#endif /* DEBUG_SW_TRACE */

    BIOS_start(); /* enable interrupts and start SYS/BIOS */

    return 0; // never executed
}

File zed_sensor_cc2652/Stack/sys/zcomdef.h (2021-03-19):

/******************************************************************************

 @file  zcomdef.h

 @brief Type definitions and macros.

 Group: CMCU, LPRF
 Target Device: CC2652

 ******************************************************************************

 Copyright (c) 2004-2018, Texas Instruments Incorporated
 All rights reserved.

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
 *  Neither the name of Texas Instruments Incorporated nor the names of
    its contributors may be used to endorse or promote products derived
    from this software without specific prior written permission.

 THIS SOFTWARE IS PROVIDED BY THE COPYRIGHT HOLDERS AND CONTRIBUTORS "AS IS"
 AND ANY EXPRESS OR IMPLIED WARRANTIES, INCLUDING, BUT NOT LIMITED TO,
 THE IMPLIED WARRANTIES OF MERCHANTABILITY AND FITNESS FOR A PARTICULAR
 PURPOSE ARE DISCLAIMED. IN NO EVENT SHALL THE COPYRIGHT OWNER OR
 CONTRIBUTORS BE LIABLE FOR ANY DIRECT, INDIRECT, INCIDENTAL, SPECIAL,
 EXEMPLARY, OR CONSEQUENTIAL DAMAGES (INCLUDING, BUT NOT LIMITED TO,
 PROCUREMENT OF SUBSTITUTE GOODS OR SERVICES; LOSS OF USE, DATA, OR PROFITS;
 OR BUSINESS INTERRUPTION) HOWEVER CAUSED AND ON ANY THEORY OF LIABILITY,
 WHETHER IN CONTRACT, STRICT LIABILITY, OR TORT (INCLUDING NEGLIGENCE OR
 OTHERWISE) ARISING IN ANY WAY OUT OF THE USE OF THIS SOFTWARE,
 EVEN IF ADVISED OF THE POSSIBILITY OF SUCH DAMAGE.

 ******************************************************************************
 Release Name: simplelink_cc26x2_sdk_1_60_00_43_s
 Release Date: 2018-01-12 15:26:58
 *****************************************************************************/

#ifndef ZCOMDEF_H
#define ZCOMDEF_H

#ifdef __cplusplus
extern "C"
{
#endif


/*********************************************************************
 * INCLUDES
 */
#include "comdef.h"
#include "saddr.h"


/*********************************************************************
 * CONSTANTS
 */
#define osal_cpyExtAddr(a, b)   sAddrExtCpy((a), (const uint8_t *)(b))
#define osal_ExtAddrEqual(a, b) sAddrExtCmp((const uint8_t *)(a), (const uint8_t *)(b))
#define osal_copyAddress(a, b)  sAddrCpy( (sAddr_t *)(a), (const sAddr_t *)(b) )

/*********************************************************************
 * CONSTANTS
 */

// Build Device Types - Used during compilation
//   These are the types of devices to build
//   Bit masked into ZSTACK_DEVICE_BUILD
#define DEVICE_BUILD_COORDINATOR    0x01
#define DEVICE_BUILD_ROUTER         0x02
#define DEVICE_BUILD_ENDDEVICE      0x04

/*** Return Values ***/
#define ZSUCCESS                  SUCCESS

/*** Component IDs ***/
#define COMPID_OSAL               0
#define COMPID_MTEL               1
#define COMPID_MTSPCI             2
#define COMPID_NWK                3
#define COMPID_NWKIF              4
#define COMPID_MACCB              5
#define COMPID_MAC                6
#define COMPID_APP                7
#define COMPID_TEST               8

#define COMPID_RTG                9
#define COMPID_DATA               11

/* Temp CompIDs for testing */
#define COMPID_TEST_NWK_STARTUP           20
#define COMPID_TEST_SCAN_CONFIRM          21
#define COMPID_TEST_ASSOC_CONFIRM         22
#define COMPID_TEST_REMOTE_DATA_CONFIRM   23

// OSAL NV Item IDs
#define ZCD_NV_EX_LEGACY                  0x0000
#define ZCD_NV_EX_ADDRMGR                 0x0001
#define ZCD_NV_EX_BINDING_TABLE           0x0002
#define ZCD_NV_EX_DEVICE_LIST             0x0003
#define ZCD_NV_EX_TCLK_TABLE              0x0004
#define ZCD_NV_EX_TCLK_IC_TABLE           0x0005
#define ZCD_NV_EX_APS_KEY_DATA_TABLE      0x0006
#define ZCD_NV_EX_NWK_SEC_MATERIAL_TABLE  0x0007

// ZCL Port NV IDs (Application Layer NV Items)
#define ZCL_PORT_SCENE_TABLE_NV_ID        0x0001
#define ZCL_PORT_PROXY_TABLE_NV_ID        0x0002
#define ZCL_PORT_SINK_TABLE_NV_ID         0x0003

// OSAL NV item IDs
#define ZCD_NV_EXTADDR                    0x0001
#define ZCD_NV_BOOTCOUNTER                0x0002
#define ZCD_NV_STARTUP_OPTION             0x0003
#define ZCD_NV_START_DELAY                0x0004

// NWK Layer NV item IDs
#define ZCD_NV_NIB                        0x0021
#define ZCD_NV_DEVICE_LIST                0x0022
#define ZCD_NV_ADDRMGR                    0x0023
#define ZCD_NV_POLL_RATE_OLD16            0x0024 // Deprecated when poll rate changed from 16 to 32 bits
#define ZCD_NV_POLL_RATE                  0x0035
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

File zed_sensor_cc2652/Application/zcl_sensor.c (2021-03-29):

/**************************************************************************************************
  Filename:       zcl_sampletemperaturesensor.c
  Revised:        $Date: 2014-10-24 16:04:46 -0700 (Fri, 24 Oct 2014) $
  Revision:       $Revision: 40796 $

  Description:    Zigbee Cluster Library - sample device application.


  Copyright 2013 Texas Instruments Incorporated. All rights reserved.

  IMPORTANT: Your use of this Software is limited to those specific rights
  granted under the terms of a software license agreement between the user
  who downloaded the software, his/her employer (which must be your employer)
  and Texas Instruments Incorporated (the "License").  You may not use this
  Software unless you agree to abide by the terms of the License. The License
  limits your use, and you acknowledge, that the Software may not be modified,
  copied or distributed unless embedded on a Texas Instruments microcontroller
  or used solely and exclusively in conjunction with a Texas Instruments radio
  frequency transceiver, which is integrated into your product.  Other than for
  the foregoing purpose, you may not use, reproduce, copy, prepare derivative
  works of, modify, distribute, perform, display or sell this Software and/or
  its documentation for any purpose.

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
  Should you have any questions regarding your right to use this Software,
  contact Texas Instruments Incorporated at www.TI.com.
**************************************************************************************************/

/*********************************************************************
  This application implements a ZigBee Temperature Sensor, based on Z-Stack 3.0.

  This application is based on the common sample-application user interface. Please see the main
  comment in zcl_sampleapp_ui.c. The rest of this comment describes only the content specific for
  this sample application.

  Application-specific UI peripherals being used:

  - LEDs:
    LED1 is not used in this application

  Application-specific menu system:

    <SET LOCAL TEMP> Set the temperature of the local temperature sensor
      Up/Down changes the temperature
      This screen shows the following information:
        Line2:
          Shows the temperature of the local temperature sensor

*********************************************************************/

/*********************************************************************
 * INCLUDES
 */
#include <Application/zcl_sensor.h>
#include "rom_jt_154.h"
#include "zcomdef.h"
#include "zcl.h"
#include "zcl_general.h"
#include "zcl_ha.h"
#include "zcl_ms.h"
#include <string.h>

#include "bdb_interface.h"
#include "bdb_reporting.h"
#include "ti_drivers_config.h"

#include <ti/drivers/apps/Button.h>
#include <ti/drivers/apps/LED.h>

#ifndef CUI_DISABLE
#include "zcl_sampleapps_ui.h"
#include "zcl_sample_app_def.h"
#endif

#include "nvintf.h"
#include "zstackmsg.h"
#include "zcl_port.h"

#include <ti/sysbios/BIOS.h>
#include <ti/sysbios/knl/Semaphore.h>
#include <ti/sysbios/knl/Task.h>
#include "zstackapi.h"
#include "util_timer.h"
#include "mac_util.h"

#if !defined (DISABLE_GREENPOWER_BASIC_PROXY) && (ZG_BUILD_RTR_TYPE)
#include "gp_common.h"
#endif

#if defined ( BDB_TL_INITIATOR )
#include "touchlink_initiator_app.h"
#elif defined ( BDB_TL_TARGET )
#include "touchlink_target_app.h"
#endif

#if defined(SENSOR_AHT10)
#include <Application/sensor_controller/AHT10/scif.h>
#elif defined(SENSOR_SI7021)
#include <Application/sensor_controller/SI7021/scif.h>
#elif defined(SENSOR_LTR390)
#include <Application/sensor_controller/LTR390/scif.h>
#elif defined(SENSOR_APDS9930)
#include <Application/sensor_controller/ADPS9930/scif.h>
#endif

/* Driver Header files */
#include <ti/drivers/ADC.h>
/* Driver configuration */
#include "ti_drivers_config.h"

#include "math.h"

/*********************************************************************
 * MACROS
 */
#define GUI_LOCAL_TEMP    1

#define APP_TITLE "   Temp Sensor  "

/*********************************************************************
 * CONSTANTS
 */

/*********************************************************************
 * TYPEDEFS
 */

/*********************************************************************
 * GLOBAL VARIABLES
 */

#ifdef SENSOR_AHT10
int32_t prev_temp = 0;
int32_t prev_hum = 0;
SCIF_I2C_TEMP_AND_HUMIDITY_SENSOR_OUTPUT_T output;
#elif defined(SENSOR_SI7021)
int32_t prev_temp = 0;
int32_t prev_hum = 0;
SCIF_I2C_TEMP_AND_HUMIDITY_SENSOR_OUTPUT_T output;
#elif defined(SENSOR_LTR390) || defined(SENSOR_APDS9930)
int32_t prev_lux = 0;
SCIF_I2C_TEMP_AND_HUMIDITY_SENSOR_OUTPUT_T output;
#endif

// Semaphore used to post events to the sensor application thread
static Semaphore_Handle appSensorSemHandle;
static Semaphore_Struct appSensorSem;

/* ADC conversion result variables */
uint16_t adcValue0;
uint32_t adcValue0MicroVolt;
uint16_t batt = 0;
uint16_t batt_prev = 0;

void scTaskAlertCallback(void);

LED_Handle gGreenLedHandle;

/*********************************************************************
 * GLOBAL FUNCTIONS
 */

/*********************************************************************
 * LOCAL VARIABLES
 */

static bool onNwk = false;

#ifdef BDB_REPORTING
#if BDBREPORTING_MAX_ANALOG_ATTR_SIZE == 8
  uint8_t reportableChange[] = {0x2C, 0x01, 0x00, 0x00, 0x00, 0x00, 0x00, 0x00}; // 0x2C01 is 300 in int16_t
#endif
#if BDBREPORTING_MAX_ANALOG_ATTR_SIZE == 4
//  uint8_t reportableChange[] = {0x2C, 0x01, 0x00, 0x00}; // 0x2C01 is 300 in int16_t
  uint8_t reportableChange[] = {0x32, 0x00, 0x00, 0x00}; // 50 in int16_t
#endif
#if BDBREPORTING_MAX_ANALOG_ATTR_SIZE == 2
  uint8_t reportableChange[] = {0x2C, 0x01}; // 0x2C01 is 300 in int16_t
#endif
#endif


// Semaphore used to post events to the application thread
static Semaphore_Handle appSemHandle;
static Semaphore_Struct appSem;

/* App service ID used for messaging with stack service task */
static uint8_t  appServiceTaskId;
/* App service task events, set by the stack service task when sending a message */
static uint32_t appServiceTaskEvents;
static endPointDesc_t  zclSensorEpDesc = {0};

#if ZG_BUILD_ENDDEVICE_TYPE
static Clock_Handle EndDeviceRejoinClkHandle;
static Clock_Struct EndDeviceRejoinClkStruct;
#endif

//#ifndef CUI_DISABLE
static uint16_t zclSensor_BdbCommissioningModes;
//#endif

// Passed in function pointers to the NV driver
static NVINTF_nvFuncts_t *pfnZdlNV = NULL;

#ifndef CUI_DISABLE
CONST char zclSampleTemperatureSensor_appStr[] = APP_TITLE_STR;
CUI_clientHandle_t gCuiHandle;
static uint32_t gSampleTemperatureSensorInfoLine;
#endif
/*********************************************************************
 * LOCAL FUNCTIONS
 */
static void zclSensor_Init( void );
static void zclSensor_initialization(void);
static void zclSensor_process_loop(void);
static void zclSensor_initParameters(void);
static void zclSensor_ProcessCommissioningStatus(bdbCommissioningModeMsg_t *bdbCommissioningModeMsg);
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

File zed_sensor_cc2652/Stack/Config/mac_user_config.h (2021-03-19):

/******************************************************************************

 @file  mac_user_config.h

 @brief This file contains user configurable variables for the MAC
        radio such as type of RF Front End used with the TI device,
        TX power table, etc. Please see below for more detail.

        To change the default values of configurable variables:
          - Include the followings in your application main.c file:
            #ifndef USE_DEFAULT_USER_CFG

            #include "mac_user_config.h"

            // MAC user defined configuration
            macUserCfg_t macUser0Cfg = MAC_USER_CFG;

            #endif // USE_DEFAULT_USER_CFG

        Note: User configurable variables except the elements of
              the power table are only used during the initialization
              of the MAC. Changing the values of these variables
              except power table elements after this will have no
              effect.

        Note: To use the default user configurable variables, define
              the preprocessor symbol USE_DEFAULT_USER_CFG in your
              application project.

 Group: WCS LPC
 Target Device: cc13x2_26x2

 ******************************************************************************
 
 Copyright (c) 2016-2020, Texas Instruments Incorporated
 All rights reserved.

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
 *  Neither the name of Texas Instruments Incorporated nor the names of
    its contributors may be used to endorse or promote products derived
    from this software without specific prior written permission.

 THIS SOFTWARE IS PROVIDED BY THE COPYRIGHT HOLDERS AND CONTRIBUTORS "AS IS"
 AND ANY EXPRESS OR IMPLIED WARRANTIES, INCLUDING, BUT NOT LIMITED TO,
 THE IMPLIED WARRANTIES OF MERCHANTABILITY AND FITNESS FOR A PARTICULAR
 PURPOSE ARE DISCLAIMED. IN NO EVENT SHALL THE COPYRIGHT OWNER OR
 CONTRIBUTORS BE LIABLE FOR ANY DIRECT, INDIRECT, INCIDENTAL, SPECIAL,
 EXEMPLARY, OR CONSEQUENTIAL DAMAGES (INCLUDING, BUT NOT LIMITED TO,
 PROCUREMENT OF SUBSTITUTE GOODS OR SERVICES; LOSS OF USE, DATA, OR PROFITS;
 OR BUSINESS INTERRUPTION) HOWEVER CAUSED AND ON ANY THEORY OF LIABILITY,
 WHETHER IN CONTRACT, STRICT LIABILITY, OR TORT (INCLUDING NEGLIGENCE OR
 OTHERWISE) ARISING IN ANY WAY OUT OF THE USE OF THIS SOFTWARE,
 EVEN IF ADVISED OF THE POSSIBILITY OF SUCH DAMAGE.

 ******************************************************************************
 
 
 *****************************************************************************/

#ifndef MAC_USER_CONFIG_H
#define MAC_USER_CONFIG_H

#ifdef __cplusplus
extern "C"
{
#endif

/*******************************************************************************
 * INCLUDES
 */
#include <chipinfo.h>
#include "api_mac.h"

/* REGULAR PROJECTS */
#if !defined( COPROCESSOR ) && !defined( LIBRARY )
#include "ti_154stack_config.h"
#endif

/* there is no patch for CC1352 */
//#include <rf_patches/rf_patch_cpe_prop.h>


#ifndef USE_DMM
#include <ti/drivers/rf/RF.h>
#else
#include "rf_mac_api.h"
#endif //USE_DMM
#include DeviceFamily_constructPath(driverlib/rf_ieee_cmd.h)
#include DeviceFamily_constructPath(driverlib/rf_prop_cmd.h)

/*******************************************************************************
 * MACROS
 */

/*******************************************************************************
 * CONSTANTS
 */

//
// Device Package and Evaluation Module (EM) Board
//
// The device may come in more than one types of packages.
// For each package, the user may change how the RF Front End (FE) is
// configured. The possible FE settings are provided as a set of defines.
// (The user can also set the FE bias, the settings of which are also provided
// as defines.) The user can change the value of RF_FE_MODE_AND_BIAS to
// configure the RF FE as desired. However, while setting the FE configuration
// determines how the device is configured at the package, it is the PCB the
// device is mounted on (the EM) that determines how those signals are routed.
// So while the FE is configurable, how signals are used is fixed by the EM.
// As can be seen, the value of RF_FE_MODE_AND_BIAS is organized by the EM
// board as defined by EMs produced by Texas Instruments Inc. How the device
// is mounted, routed, and configured for a user product would of course be
// user defined, and the value of RF_FE_MODE_AND_BIAS would have to be set
// accordingly; the user could even dispense with the conditional board
// compiles entirely. So too with the usage of the Tx Power tables. As can be
// seen in mac_user_config.c, there are two tables, one for packages using a
// differential FE, and one for single-end. This too has been organized by TI
// defined EMs and would have to be set appropriately by the user.


/*******************************************************************************
 * TYPEDEFS
 */
/* Alternate HAL Assert function pointer */
typedef void (*alternateHalAssertFp_t)(void);
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

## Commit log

2021-03-19 add Sensor Controller Code for the i2c sensors
2021-03-23 add kicad schematic and pcb for rf_star cc2652 daughter card
    [daughter_board-B_Cu.gbr, daughter_board-B_Mask.gbr, daughter_board-B_Paste.gbr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]
2021-03-23 add stand-alone cc2652 kicad schematic and pcb
    [zigbee.kicad_pcb, zigbee.sch]
2021-03-24 update pcb of zed add devices.js mods for zigbee2mqtt
    [zigbee.kicad_pcb]
2021-03-26 zed reports illuminance (lux) from LTR390 sensor
2021-03-29 add adps9930 light sensor to sensor controller
2021-03-29 add ALC sensor code to cc2652
2021-03-29 update sensor controller defaults
